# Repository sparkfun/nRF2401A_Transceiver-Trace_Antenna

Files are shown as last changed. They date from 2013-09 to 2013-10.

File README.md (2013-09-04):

nRF2401A Transceiver- Trace Antenna
==================================
[nRF2401A Transceiver Trace Antenna  
*nRF2401A Transceiver with Trace Antenna (WRL-00153)*](https://github.com/sparkfun/nRF2401A_Transceiver-Trace_Antenna)

This is a breakout board for the nRF2401A 2.4GHz transceiver module with a built-in trace antenna. 

Repository Contents
-------------------
* **/Firmware** - Example firmware to use with the chip
* **/Hardware** - All Eagle design files (.brd, .sch)

License Information
-------------------
The hardware is released under [Creative Commons Share-alike 3.0](http://creativecommons.org/licenses/by-sa/3.0/).  
All other code is open source so please feel free to do anything you want with it; 
you buy me a beer if you use this and we meet someday ([Beerware license](http://en.wikipedia.org/wiki/Beerware)).

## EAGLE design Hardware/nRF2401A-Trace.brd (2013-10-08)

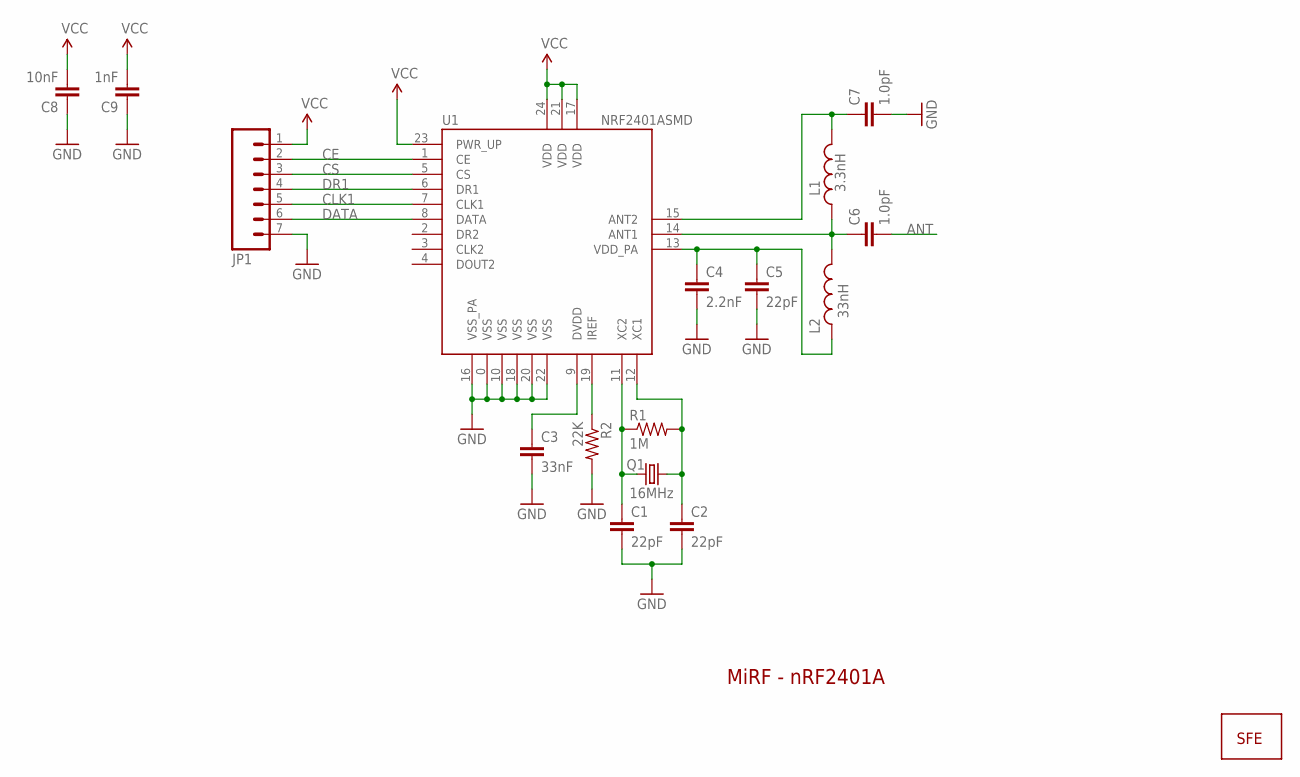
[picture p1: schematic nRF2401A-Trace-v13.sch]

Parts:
C1, C2, C5: 22pF; 0402-CAP
C3: 33nF; 0402-CAP
C4: 2.2nF; 0402-CAP
C6, C7: 1.0pF; 0402-CAP
C8: 10nF; 0402-CAP
C9: 1nF; 0402-CAP
JP1: M07; 1X07
L1: 3.3nH; C0402
L2: 33nH; C0402
Q1: 16MHz; CRYSTAL-SMD-5X3
R1: 1M; 0402-RES
R2: 22K; 0402-RES
U1: NRF2401ASMD; MLP-24
U$1: LOGO-SFESK; SFE-LOGO-FLAME

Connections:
ANT: C6.2
CE: JP1.2, U1.1 (CE)
CLK1: JP1.5, U1.7 (CLK1)
CS: JP1.3, U1.5 (CS)
DATA: JP1.6, U1.8 (DATA)
DR1: JP1.4, U1.6 (DR1)
GND: C1.2, C2.2, C3.2, C4.2, C5.2, C7.2, C8.1, C9.1, JP1.7, R2.2, U1.0 (VSS), U1.10 (VSS), U1.16 (VSS_PA), U1.18 (VSS), U1.20 (VSS), U1.22 (VSS)
unnamed: C1.1, Q1.1, R1.1, U1.11 (XC2)
unnamed: C2.1, Q1.3 (2), R1.2, U1.12 (XC1)
unnamed: C6.1, L1.1, L2.2, U1.14 (ANT1)
unnamed: R2.1, U1.19 (IREF)
unnamed: C3.1, U1.9 (DVDD)
unnamed: C7.1, L1.2, U1.15 (ANT2)
unnamed: C4.1, C5.1, L2.1, U1.13 (VDD_PA)
VCC: C8.2, C9.2, JP1.1, U1.17 (VDD), U1.21 (VDD), U1.23 (PWR_UP), U1.24 (VDD)

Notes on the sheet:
MiRF - nRF2401A

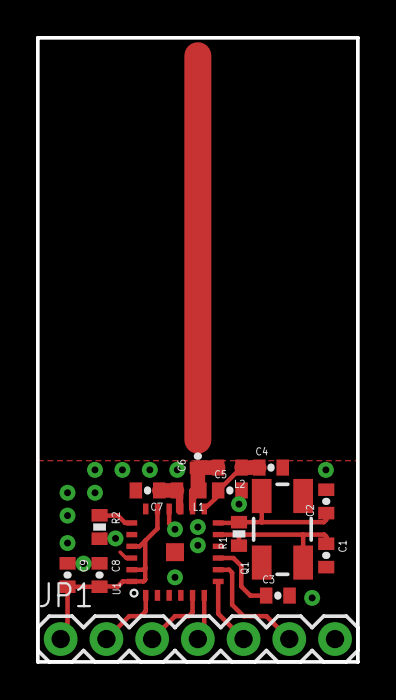
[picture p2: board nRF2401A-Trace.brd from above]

Board: 2 copper layers, 17.8 x 34.7 mm, 17 parts (1 on the bottom side), 14 nets.

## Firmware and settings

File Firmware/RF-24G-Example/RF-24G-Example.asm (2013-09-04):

; CC5X Version 3.1I, Copyright (c) B Knudsen Data
; C compiler for the PICmicro family
; ************  23. Jun 2004   9:53  *************

	processor  16F88
	radix  DEC

INDF        EQU   0x00
PCL         EQU   0x02
FSR         EQU   0x04
PORTA       EQU   0x05
TRISA       EQU   0x85
PORTB       EQU   0x06
TRISB       EQU   0x86
PCLATH      EQU   0x0A
Carry       EQU   0
Zero_       EQU   2
RP0         EQU   5
RP1         EQU   6
IRP         EQU   7
GIE         EQU   7
TMR1L       EQU   0x0E
TMR1H       EQU   0x0F
TXREG       EQU   0x19
RCREG       EQU   0x1A
OSCCON      EQU   0x8F
SPBRG       EQU   0x99
ANSEL       EQU   0x9B
CMCON       EQU   0x9C
EEDATA      EQU   0x10C
EEADR       EQU   0x10D
EEDATH      EQU   0x10E
EEADRH      EQU   0x10F
PEIE        EQU   6
TMR1IF      EQU   0
TXIF        EQU   4
RCIF        EQU   5
TMR1ON      EQU   0
CREN        EQU   4
SPEN        EQU   7
TXIE        EQU   4
RCIE        EQU   5
BRGH        EQU   2
SYNC        EQU   4
TXEN        EQU   5
RD          EQU   0
EEPGD       EQU   7
x           EQU   0x7F
x_2         EQU   0x22
y           EQU   0x24
z           EQU   0x25
x_3         EQU   0x7F
y_2         EQU   0x7F
want_ints   EQU   0
want_ints_2 EQU   0
nate        EQU   0x36
x_4         EQU   0x36
nate_2      EQU   0x26
my_byte     EQU   0x27
i           EQU   0x29
k           EQU   0x2A
m           EQU   0x2B
temp        EQU   0x2C
high_byte   EQU   0x2D
low_byte    EQU   0x2E
C1cnt       EQU   0x36
C2tmp       EQU   0x37
C3cnt       EQU   0x36
C4tmp       EQU   0x37
C5rem       EQU   0x39
data_array  EQU   0x3B
counter     EQU   0x3F
elapsed_time EQU   0x20
i_2         EQU   0x22
j           EQU   0x23
temp_2      EQU   0x24
i_3         EQU   0x22
j_2         EQU   0x23
temp_3      EQU   0x24
rf_address  EQU   0x25
i_4         EQU   0x22
config_setup EQU   0x23
i_5         EQU   0x22
config_setup_2 EQU   0x23
ci          EQU   0x36

	GOTO main

  ; FILE D:\Pics\code\16F88\RF Test\RF-24G-Example.c
			;/*
			;    5-30-04
			;    Copyright Spark Fun Electronics© 2004
			;    
			;    RF-24G Configuration and testing. The 24G requires 500ns between Data Setup and Clk, so we ran this on a 16F88 at
			;    internal 8MHz which turns into 500ns per instruction. Imagine a breadboard with a 16F88 connected to two transceivers
			;    inserted into the same breadboard about 4 inches apart. This made it easy for testing the setup on the units and 
			;    proof of transmission, but not a good setup for testing the effective communication distance.
			;    
			;    The RF-24G requires 3V!! No 5V! So we ran our 16F88 (not 16LF88) at 3V and at 8MHz. This is out of spec for both minimum 
			;    voltage (4V) and maximum frequency at 3V (4MHz) but it worked great! Of course it shouldn't be used for a deployed design.    
			;    
			;    The time delay between clocking in the next data is given by the equation on page 31.
			;    Time On Air = (databits+1) / datarate  
			;    T(OA) = 266 bits (max) / 1,000,000 bps = 266us
			;    
			;    NOTE: If you enable the receiver (set CE high), the receiver will start monitoring the air. With the CRC
			;    set to 8 bit (default) the receiver will find all sorts of junk in the air with a correct CRC tag. Our recommendation
			;    is to either transmit a resonably constant stream of data, use 16-bit CRC, and/or use additional header/end bytes in
			;    the payload to verify incoming packets.
			;    
			;
			;    config_setup word 16 bits found on pages 13-15
			;    
			;    23: 0 Payloads have an 8 bit address
			;    22: 0
			;    21: 1
			;    20: 0
			;    19: 0
			;    18: 0
			;    17: 1 16-Bit CRC
			;    16: 1 CRC Enabled
			;
			;    15: 0 One channel receive
			;    14: 1 ShockBurst Mode
			;    13: 1 1Mbps Transmission Rate
			;    12: 0
			;    11: 1
			;    10: 1
			;    9: 1 RF Output Power
			;    8: 0 RF Output Power
			;
			;    7: 0 Channel select (channel 2)
			;    6: 0
			;    5: 0
			;    4: 0
			;    3: 0
			;    2: 1
			;    1: 0
			;    0: 0 Transmit mode
			;    
			;*/
			;#define Clock_8MHz
			;#define Baud_9600
			;
			;#include "d:\Pics\c\16F88.h"
			;
			;//There is no config word because this program tested on a 16F88 using Bloader the boot load program
			;
			;#pragma origin 4
	ORG 0x0004

  ; FILE d:\Pics\code\Delay.c
			;/*
			;    7/23/02
			;    Nathan Seidle
			;    nathan.seidle@colorado.edu
			;    
			;    Delays for... Well, everything.
			;    
			;    11-11 Updated the delays - now they actually delay what they say they should.
			;    
			;    10-11-03 Updated delays. New CC5X compiler is muy optimized.
			;
			;*/
			;
			;//Really short delay
			;void delay_us(uns16 x)
			;{
_const1
	MOVWF ci
	MOVLW .0
	BSF   0x03,RP1
	MOVWF EEADRH
	BCF   0x03,RP1
	RRF   ci,W
	ANDLW .127
	ADDLW .35
	BSF   0x03,RP1
	MOVWF EEADR
	BTFSC 0x03,Carry
	INCF  EEADRH,1
	BSF   0x03,RP0
	BSF   0x18C,EEPGD
	BSF   0x18C,RD
	NOP  
	NOP  
	BCF   0x03,RP0
	BCF   0x03,RP1
	BTFSC ci,0
	GOTO  m001
	BSF   0x03,RP1
	MOVF  EEDATA,W
	ANDLW .127
	BCF   0x03,RP1
	RETURN
m001	BSF   0x03,RP1
	RLF   EEDATA,W
	RLF   EEDATH,W
	BCF   0x03,RP1
	RETURN
	DW    0x68A
	DW    0x32D3
	DW    0x326E
	DW    0x3769
	DW    0x1067
	DW    0x30E4
	DW    0x30F4
	DW    0x172E
	DW    0x52E
	DW    0xD
	DW    0x34D4
	DW    0x32ED
	DW    0x3A20
	DW    0x106F
	DW    0x32F2
	DW    0x32E3
	DW    0x3B69
	DW    0x1065
	DW    0x103D
	DW    0x3225
	DW    0x68A
	DW    0x2700
	DW    0x106F
	DW    0x30E4
	DW    0x30F4
	DW    0x3320
	DW    0x3AEF
	DW    0x326E
	DW    0x521
	DW    0xD
	DW    0x68A
	DW    0x2352
	DW    0x192D
	DW    0x23B4
	DW    0x2A20
	DW    0x39E5
	DW    0x34F4
	DW    0x33EE
	DW    0x53A
	DW    0xD
	DW    0x2944
	DW    0x3BA0
	DW    0x3765
	DW    0x1074
	DW    0x37EC
	DW    0x577
	DW    0xD
	DW    0x68A
	DW    0x30C4
	DW    0x30F4
	DW    0x2920
	DW    0x31E5
	DW    0x34E5
	DW    0x32F6
	DW    0x1D64
	DW    0x68A
	DW    0x2D80
	DW    0x2EB0
	DW    0x1D20
	DW    0x12A0
	DW    0x568
	DW    0xD
	DW    0x18DB
	DW    0x105D
	DW    0x103A
	DW    0x3425
	DW    0x68A
	DW    0x2D80
	DW    0x2EB2
	DW    0x1D20
	DW    0x12A0
	DW    0x568
	DW    0xD
	DW    0x19DB
	DW    0x105D
	DW    0x103A
	DW    0x3425
	DW    0x68A
	DW    0x2900
	DW    0x1058
	DW    0x37C3
	DW    0x336E
	DW    0x33E9
	DW    0x3975
	DW    0x3A61
	DW    0x37E9
	DW    0x106E
	DW    0x34E6
	DW    0x34EE
	DW    0x3473
	DW    0x3265
	DW    0x172E
	DW    0x52E
	DW    0xD
	DW    0x2C54
	DW    0x21A0
	DW    0x376F
	DW    0x34E6
	DW    0x3AE7
	DW    0x30F2
	DW    0x34F4
	DW    0x376F
	DW    0x3320
	DW    0x3769
	DW    0x39E9
	DW    0x32E8
	DW    0x1764
	DW    0x172E
	DW    0x68A
	DW    0x0
delay_us
			;
			;#ifdef Clock_4MHz
			;    //Calling with 10us returns 69us
			;    for ( ; x > 0 ; x--);
			;#endif
			;
			;#ifdef Clock_8MHz
			;    //Calling with 1us returns 11us
			;    //Calling with 10us returns 56us
			;    //for ( ; x > 0 ; x--);
			;    
			;    //Calling with 1us returns 7.5us
			;    //Calling with 10us returns 48
			;    //Calling with 1000us returns 4.5ms
			;    while(--x); 
m002	DECF  x,1
	INCF  x,W
	BTFSC 0x03,Zero_
	DECF  x+1,1
	MOVF  x,W
	IORWF x+1,W
	BTFSS 0x03,Zero_
	GOTO  m002
			;
			;    //while(x--); 
			;#endif
			;
			;#ifdef Clock_20MHz
			;    //Calling with 10us returns 13 us
			;    //Calling with 1us returns 1.8us
			;    while(--x) nop(); 
			;#endif
			;
			;}
	RETURN
			;
			;//General short delay
			;void delay_ms(uns16 x)
			;{
delay_ms
			;
			;#ifdef Clock_4MHz
			;    //Clocks out at 1002us per 1ms
			;    int y;
			;    for ( ; x > 0 ; x--)
			;        for ( y = 0 ; y < 108 ; y++);
			;#endif
			;
			;#ifdef Clock_8MHz
			;    //Clocks out at 1006us per 1ms
			;    uns8 y, z;
			;    for ( ; x > 0 ; x--)
m003	MOVF  x_2,W
	IORWF x_2+1,W
	BTFSC 0x03,Zero_
	GOTO  m008
			;        for ( y = 0 ; y < 4 ; y++)
	CLRF  y
m004	MOVLW .4
	SUBWF y,W
	BTFSC 0x03,Carry
	GOTO  m007
			;            for ( z = 0 ; z < 69 ; z++);
	CLRF  z
m005	MOVLW .69
	SUBWF z,W
	BTFSC 0x03,Carry
	GOTO  m006
	INCF  z,1
	GOTO  m005
m006	INCF  y,1
	GOTO  m004
m007	DECF  x_2,1
	INCF  x_2,W
	BTFSC 0x03,Zero_
	DECF  x_2+1,1
	GOTO  m003
			;#endif
			;
			;#ifdef Clock_20MHz
			;
			;    uns8 y, z;
			;    //Clocks out to 1.00ms per 1ms
			;    //9.99 ms per 10ms
			;    for ( ; x > 0 ; x--)
			;        for ( y = 0 ; y < 4 ; y++)
			;            for ( z = 0 ; z < 176 ; z++);
			;#endif
			;
			;}
m008	RETURN
			;
			;//Delays in 31.25kHz Low Power mode using the internal 31.25kHz oscillator
			;void delay_s_lp(uns16 x)
			;{
delay_s_lp
			;
			;    uns16 y;
			;    //Clocks out to 1.001s per 1s
			;    for ( ; x > 0 ; x--)
m009	MOVF  x_3,W
	IORWF x_3+1,W
	BTFSC 0x03,Zero_
	GOTO  m013
			;        for ( y = 0 ; y < 775 ; y++);
	CLRF  y_2
	CLRF  y_2+1
m010	MOVLW .3
	SUBWF y_2+1,W
	BTFSS 0x03,Carry
	GOTO  m011
	BTFSS 0x03,Zero_
	GOTO  m012
	MOVLW .7
	SUBWF y_2,W
	BTFSC 0x03,Carry
	GOTO  m012
m011	INCF  y_2,1
	BTFSC 0x03,Zero_
	INCF  y_2+1,1
	GOTO  m010
m012	DECF  x_3,1
	INCF  x_3,W
	BTFSC 0x03,Zero_
	DECF  x_3+1,1
	GOTO  m009

  ; FILE D:\Pics\code\16F88\RF Test\RF-24G-Example.c
			;
			;#include "d:\Pics\code\Delay.c"     // Delays
m013	RETURN
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
			;void main()
			;{
main
			;    uns16 elapsed_time;
			;
			;    counter = 0;
	BCF   0x03,RP0
	BCF   0x03,RP1
	CLRF  counter
			;    
			;    boot_up();
	BSF   0x03,RP0
	CALL  boot_up
			;
			;    while(1)
			;    {
			;        counter++;
m041	INCF  counter,1
			;        
			;        data_array[0] = 0x12;
	MOVLW .18
	MOVWF data_array
			;        data_array[1] = 0x34;
	MOVLW .52
	MOVWF data_array+1
			;        data_array[2] = 0xAB;
	MOVLW .171
	MOVWF data_array+2
			;        data_array[3] = counter;
	MOVF  counter,W
	MOVWF data_array+3
			;
			;        printf("\n\rSending data...\n\r", 0);
	CLRF  nate_2
	CLRF  my_byte
	CLRF  my_byte+1
	CALL  printf
			;        transmit_data();
	CALL  transmit_data
			;    
			;        //Here we monitor how many clock cycles it takes for the receiver to register good data
			;        //elasped_time is in cycles - each cycles is 500ns at 8MHz so 541 cycles = 270.5us
			;        //==============================================
			;        TMR1IF = 0;
	BCF   0x0C,TMR1IF
			;        TMR1L = 0 ; TMR1H = 0 ; TMR1ON = 1;
	CLRF  TMR1L
	CLRF  TMR1H
	BSF   0x10,TMR1ON
			;        while(RX_DR == 0)
m042	BTFSC PORTA,0
	GOTO  m043
			;            if (TMR1IF == 1) break; //If timer1 rolls over waiting for data, then break
	BTFSS 0x0C,TMR1IF
	GOTO  m042
			;        TMR1ON = 0;
m043	BCF   0x10,TMR1ON
			;        elapsed_time.high8 = TMR1H;
	MOVF  TMR1H,W
	MOVWF elapsed_time+1
			;        elapsed_time.low8 = TMR1L;
	MOVF  TMR1L,W
	MOVWF elapsed_time
			;        printf("Time to receive = %d\n\r", elapsed_time);
	MOVLW .20
	MOVWF nate_2
	MOVF  elapsed_time,W
	MOVWF my_byte
	MOVF  elapsed_time+1,W
	MOVWF my_byte+1
	CALL  printf
			;        //==============================================
			;        
			;        if(RX_DR == 1) //We have data!
	BTFSS PORTA,0
	GOTO  m044
			;            receive_data();
	CALL  receive_data
			;        else
	GOTO  m045
			;            printf("No data found!\n\r", 0);
m044	MOVLW .43
	MOVWF nate_2
	CLRF  my_byte
	CLRF  my_byte+1
	CALL  printf
			;        
			;        delay_ms(1000); //Have a second between transmissions just for evaluation
m045	MOVLW .232
	MOVWF x_2
	MOVLW .3
	MOVWF x_2+1
	CALL  delay_ms
			;    
			;    }
	GOTO  m041
			;        
			;}
			;
			;void boot_up(void)
			;{
boot_up
			;    OSCCON = 0b.0111.0000; //Setup internal oscillator for 8MHz
	MOVLW .112
	MOVWF OSCCON
			;    while(OSCCON.2 == 0); //Wait for frequency to stabilize
m046	BTFSS OSCCON,2
	GOTO  m046
			;
			;    ANSEL = 0b.0000.0000; //Turn pins to Digital instead of Analog
	CLRF  ANSEL
			;    CMCON = 0b.0000.0111; //Turn off comparator on RA port
	MOVLW .7
	MOVWF CMCON
			;
			;    PORTA = 0b.0000.0000;  
	BCF   0x03,RP0
	CLRF  PORTA
			;    TRISA = 0b.0000.0001;  //0 = Output, 1 = Input (RX_DR is on RA0)
	MOVLW .1
	BSF   0x03,RP0
	MOVWF TRISA
			;
			;    PORTB = 0b.0000.0000;  
	BCF   0x03,RP0
	CLRF  PORTB
			;    TRISB = 0b.0000.0100;  //0 = Output, 1 = Input (RX is an input)
	MOVLW .4
	BSF   0x03,RP0
	MOVWF TRISB
			;
			;    enable_uart_TX(0); //Setup the hardware UART for 20MHz at 9600bps
	BCF   0x03,RP0
	BCF   0x22,want_ints
	BSF   0x03,RP0
	CALL  enable_uart_TX
			;    enable_uart_RX(0); //Take a look at header files - it's not that hard to setup the UART
	BCF   0x03,RP0
	BCF   0x22,want_ints_2
	BSF   0x03,RP0
	CALL  enable_uart_RX
			;    
			;    printf("\n\rRF-24G Testing:\n\r", 0);
	MOVLW .60
	MOVWF nate_2
	CLRF  my_byte
	CLRF  my_byte+1
	CALL  printf
			;    
			;    delay_ms(100);
	MOVLW .100
	MOVWF x_2
	CLRF  x_2+1
	CALL  delay_ms
			;
			;    configure_transmitter();
	CALL  configure_transmitter
			;    configure_receiver();
	GOTO  configure_receiver
			;
			;}
			;
			;//This will clock out the current payload into the data_array
			;void receive_data(void)
			;{
receive_data
			;    uns8 i, j, temp;
			;
			;    RX_CE = 0;//Power down RF Front end
	BCF   PORTA,2
			;
			;    //Erase the current data array so that we know we are looking at actual received data
			;    data_array[0] = 0x00;
	CLRF  data_array
			;    data_array[1] = 0x00;
	CLRF  data_array+1
			;    data_array[2] = 0x00;
	CLRF  data_array+2
			;    data_array[3] = 0x00;
	CLRF  data_array+3
			;
			;    //Clock in data, we are setup for 32-bit payloads
			;    for(i = 0 ; i < 4 ; i++) //4 bytes
	CLRF  i_2
m047	MOVLW .4
	SUBWF i_2,W
	BTFSC 0x03,Carry
	GOTO  m050
			;    {
			;        for(j = 0 ; j < 8 ; j++) //8 bits each
	CLRF  j
m048	MOVLW .8
	SUBWF j,W
	BTFSC 0x03,Carry
	GOTO  m049
			;        {
			;            temp <<= 1;
	BCF   0x03,Carry
	RLF   temp_2,1
			;            temp.0 = RX_DATA;
	BCF   temp_2,0
	BTFSC PORTA,1
	BSF   temp_2,0
			;
			;            RX_CLK1 = 1;
	BSF   PORTA,4
			;            RX_CLK1 = 0;
	BCF   PORTA,4
			;        }
	INCF  j,1
	GOTO  m048
			;
			;        data_array[i] = temp; //Store this byte
m049	MOVLW .59
	ADDWF i_2,W
	MOVWF FSR
	BCF   0x03,IRP
	MOVF  temp_2,W
	MOVWF INDF
			;    }
	INCF  i_2,1
	GOTO  m047
			;    
			;    if(RX_DR == 0) //Once the data is clocked completely, the receiver should make DR go low
m050	BTFSC PORTA,0
	GOTO  m051
			;        printf("DR went low\n\r", 0);
	MOVLW .80
	MOVWF nate_2
	CLRF  my_byte
	CLRF  my_byte+1
	CALL  printf
			;    
			;    printf("\n\rData Received:\n\r", 0);
m051	MOVLW .94
	MOVWF nate_2
	CLRF  my_byte
	CLRF  my_byte+1
	CALL  printf
			;    printf("[0] : %h\n\r", data_array[0]);
	MOVLW .113
	MOVWF nate_2
	MOVF  data_array,W
	MOVWF my_byte
	CLRF  my_byte+1
	CALL  printf
			;    printf("[1] : %h\n\r", data_array[1]);
	MOVLW .124
	MOVWF nate_2
	MOVF  data_array+1,W
	MOVWF my_byte
	CLRF  my_byte+1
	CALL  printf
			;    printf("[2] : %h\n\r", data_array[2]);
	MOVLW .135
	MOVWF nate_2
	MOVF  data_array+2,W
	MOVWF my_byte
	CLRF  my_byte+1
	CALL  printf
			;    printf("[3] : %h\n\r", data_array[3]);
	MOVLW .146
	MOVWF nate_2
	MOVF  data_array+3,W
	MOVWF my_byte
	CLRF  my_byte+1
	CALL  printf
			;
			;    RX_CE = 1; //Power up RF Front end
	BSF   PORTA,2
			;}
	RETURN
			;
			;//This sends out the data stored in the data_array
			;//data_array must be setup before calling this function
			;void transmit_data(void)
			;{
transmit_data
			;    uns8 i, j, temp, rf_address;
			;
			;    TX_CE = 1;
	BSF   PORTB,0
			;
			;    //Clock in address
			;    rf_address = 0b.1110.0111; //Power-on Default for all units (on page 11)
	MOVLW .231
	MOVWF rf_address
			;    for(i = 0 ; i < 8 ; i++)
	CLRF  i_3
m052	MOVLW .8
	SUBWF i_3,W
	BTFSC 0x03,Carry
	GOTO  m053
			;    {
			;        TX_DATA = rf_address.7;
	BTFSS rf_address,7
	BCF   PORTB,4
	BTFSC rf_address,7
	BSF   PORTB,4
			;        TX_CLK1 = 1;
	BSF   PORTB,3
			;        TX_CLK1 = 0;
	BCF   PORTB,3
			;        
			;        rf_address <<= 1;
	BCF   0x03,Carry
	RLF   rf_address,1
			;    }
	INCF  i_3,1
	GOTO  m052
			;    
			;    //Clock in the data_array
			;    for(i = 0 ; i < 4 ; i++) //4 bytes
m053	CLRF  i_3
m054	MOVLW .4
	SUBWF i_3,W
	BTFSC 0x03,Carry
	GOTO  m057
			;    {
			;        temp = data_array[i];
	MOVLW .59
	ADDWF i_3,W
	MOVWF FSR
	BCF   0x03,IRP
	MOVF  INDF,W
	MOVWF temp_3
			;        
			;        for(j = 0 ; j < 8 ; j++) //One bit at a time
	CLRF  j_2
m055	MOVLW .8
	SUBWF j_2,W
	BTFSC 0x03,Carry
	GOTO  m056
			;        {
			;            TX_DATA = temp.7;
	BTFSS temp_3,7
	BCF   PORTB,4
	BTFSC temp_3,7
	BSF   PORTB,4
			;            TX_CLK1 = 1;
	BSF   PORTB,3
			;            TX_CLK1 = 0;
	BCF   PORTB,3
			;            
			;            temp <<= 1;
	BCF   0x03,Carry
	RLF   temp_3,1
			;        }
	INCF  j_2,1
	GOTO  m055
			;    }
m056	INCF  i_3,1
	GOTO  m054
			;    
			;    TX_CE = 0; //Start transmission   
m057	BCF   PORTB,0
			;}
	RETURN
			;
			;//2.4G Configuration - Receiver
			;//This setups up a RF-24G for receiving at 1mbps
			;void configure_receiver(void)
			;{
configure_receiver
			;    uns8 i;
			;    uns24 config_setup;
			;
			;    //During configuration of the receiver, we need RX_DATA as an output
			;    PORTA = 0b.0000.0000;  
	CLRF  PORTA
			;    TRISA = 0b.0000.0001;  //0 = Output, 1 = Input (RX_DR is on RA0) (RX_DATA is on RA1)
	MOVLW .1
	BSF   0x03,RP0
	MOVWF TRISA
			;
			;    //Config Mode
			;    RX_CE = 0; RX_CS = 1;
	BCF   0x03,RP0
	BCF   PORTA,2
	BSF   PORTA,3
			;    
			;    //Delay of 5us from CS to Data (page 30) is taken care of by the for loop
			;    
			;    //Setup configuration word
			;    config_setup = 0b.0010.0011.0110.1110.0000.0101; //Look at pages 13-15 for more bit info
	MOVLW .5
	MOVWF config_setup
	MOVLW .110
	MOVWF config_setup+1
	MOVLW .35
	MOVWF config_setup+2
			;
			;    for(i = 0 ; i < 24 ; i++)
	CLRF  i_4
m058	MOVLW .24
	SUBWF i_4,W
	BTFSC 0x03,Carry
	GOTO  m059
			;    {
			;        RX_DATA = config_setup.23;
	BTFSS config_setup+2,7
	BCF   PORTA,1
	BTFSC config_setup+2,7
	BSF   PORTA,1
			;        RX_CLK1 = 1;
	BSF   PORTA,4
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

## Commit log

2013-09-04 Initial file commit
    [nRF2401A-Trace-v13.sch]
2013-10-08 Adding .brd file to Hardware
    [nRF2401A-Trace.brd]
